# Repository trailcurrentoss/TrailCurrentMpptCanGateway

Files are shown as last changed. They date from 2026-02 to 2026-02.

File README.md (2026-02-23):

# TrailCurrent MPPT CAN Gateway

Gateway module that reads data from a Victron MPPT (Maximum Power Point Tracker) solar charge controller via serial and relays the readings over a CAN bus interface. Part of the [TrailCurrent](https://trailcurrent.com) open-source vehicle platform.

## Hardware Overview

- **Microcontroller:** ESP32
- **Function:** Serial-to-CAN bus bridge for Victron MPPT solar charge controller data
- **Key Features:**
  - Victron MPPT VE.Direct serial protocol parsing
  - CAN bus output at 500 kbps
  - Real-time solar panel monitoring
  - Hierarchical PCB schematic design

## Hardware Requirements

### Components

- **Microcontroller:** ESP32 development board
- **CAN Transceiver:** Vehicle CAN bus interface (TX: GPIO 15, RX: GPIO 13)
- **Serial Input:** Victron MPPT VE.Direct connection (Serial2: TX GPIO 17, RX GPIO 16 at 19200 baud)

### KiCAD Library Dependencies

This project uses the consolidated [TrailCurrentKiCADLibraries](https://github.com/trailcurrentoss/TrailCurrentKiCADLibraries).

**Setup:**

```bash
# Clone the library
git clone git@github.com:trailcurrentoss/TrailCurrentKiCADLibraries.git

# Set environment variables (add to ~/.bashrc or ~/.zshrc)
export TRAILCURRENT_SYMBOL_DIR="/path/to/TrailCurrentKiCADLibraries/symbols"
export TRAILCURRENT_FOOTPRINT_DIR="/path/to/TrailCurrentKiCADLibraries/footprints"
export TRAILCURRENT_3DMODEL_DIR="/path/to/TrailCurrentKiCADLibraries/3d_models"
```

See [KICAD_ENVIRONMENT_SETUP.md](https://github.com/trailcurrentoss/TrailCurrentKiCADLibraries/blob/main/KICAD_ENVIRONMENT_SETUP.md) in the library repository for detailed setup instructions.

## Opening the Project

1. **Set up environment variables** (see Library Dependencies above)
2. **Open KiCAD:**
   ```bash
   kicad EDA/trailer-mppt-can-bus.kicad_pro
   ```
3. **Verify libraries load** - All symbol and footprint libraries should resolve without errors
4. **View 3D models** - Open PCB and press `Alt+3` to view the 3D visualization

### Schematic Sheets

The design uses a hierarchical schematic with dedicated sheets:
- **Root** - Top-level connections
- **Power** - Power distribution and regulation
- **CAN** - CAN bus transceiver interface
- **MCU** - ESP32 microcontroller and support circuits
- **Connectivity** - Serial interface to Victron MPPT

## Firmware

See `src/` directory for PlatformIO-based firmware.

**Setup:**
```bash
# Install PlatformIO (if not already installed)
pip install platformio

# Build firmware
pio run

# Upload to board
pio run -t upload
```

### Victron MPPT Parameters

The firmware parses the following VE.Direct protocol fields:

| Parameter | Description |
|---|---|
| V | Battery voltage |
| VPV | Panel voltage |
| PPV | Panel power (watts) |
| I | Panel current |
| CS | Charge state |
| ERR | Error code |
| H19-H23 | Historical yield and power data |

### CAN Bus Protocol

The gateway transmits two messages at 500 kbps with a 33ms update cycle:

**Message 0x2C** (7 bytes) - Solar panel basics:

| Byte | Description |
|---|---|
| 0-1 | Panel voltage |
| 2-3 | Solar watts |
| 4-5 | Battery voltage |
| 6 | Solar status |

**Message 0x2D** (3 bytes) - Solar current:

| Byte | Description |
|---|---|
| 0 | Current sign |
| 1-2 | Current magnitude |

## Manufacturing

- **PCB Files:** Ready for fabrication via standard PCB services (JLCPCB, OSH Park, etc.)
- **BOM Generation:** Export BOM from KiCAD schematic (Tools > Generate BOM)
- **JLCPCB Assembly:** See [BOM_ASSEMBLY_WORKFLOW.md](https://github.com/trailcurrentoss/TrailCurrentKiCADLibraries/blob/main/BOM_ASSEMBLY_WORKFLOW.md) for detailed assembly workflow

## Project Structure

```
├── EDA/                          # KiCAD hardware design files
│   ├── trailer-mppt-can-bus.kicad_pro
│   ├── trailer-mppt-can-bus.kicad_sch  # Root schematic
│   ├── can.kicad_sch             # CAN subsystem
│   ├── connectivity.kicad_sch    # Serial interface
│   ├── mcu.kicad_sch             # MCU subsystem
│   ├── power.kicad_sch           # Power subsystem
│   └── trailer-mppt-can-bus.kicad_pcb  # PCB layout
├── src/                          # Firmware source
│   ├── main.cpp                  # Victron MPPT parser and CAN transmitter
│   ├── globals.h                 # Debug macros
│   └── canHelper.h               # CAN bus configuration
└── platformio.ini                # Build configuration
```

## License

MIT License - See LICENSE file for details.

This is open source hardware. You are free to use, modify, and distribute these designs under the terms of the MIT license.

## Contributing

Improvements and contributions are welcome! Please submit issues or pull requests.

## Support

For questions about:
- **KiCAD setup:** See [KICAD_ENVIRONMENT_SETUP.md](https://github.com/trailcurrentoss/TrailCurrentKiCADLibraries/blob/main/KICAD_ENVIRONMENT_SETUP.md)
- **Assembly workflow:** See [BOM_ASSEMBLY_WORKFLOW.md](https://github.com/trailcurrentoss/TrailCurrentKiCADLibraries/blob/main/BOM_ASSEMBLY_WORKFLOW.md)

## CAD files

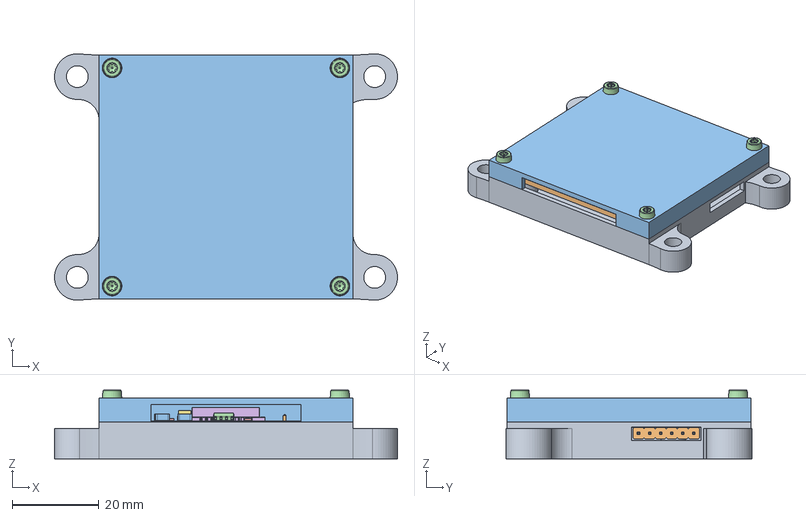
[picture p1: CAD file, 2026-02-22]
CAD/trailcurrent-shunt-can-bus-housing.FCStd
78.9 x 56.7 x 15.8 mm
BodyCaseBottom
Pcb_7b99
C5_C_1206_3216Metric_9f1fbb0e91b7 x 6
U2_SOIC_8_39x49mm_P127mm_3940626bae83
R4_R_1206_3216Metric_6f3765b3a8a0 x 2
AP63203WU-7
AP63203WU-008
AP63203WU-009
AP63203WU-010
AP63203WU-011
AP63203WU-012
AP63203WU-013
AP63203WU-014
U1_ESP32-WROOM-32_805435b90435
FilletPin1
FilletPin2
J1_PinHeader_1x06_P254mm_Horizontal_b900b64528b3
BodyCaseCover
M2.5x8-Screw x 4

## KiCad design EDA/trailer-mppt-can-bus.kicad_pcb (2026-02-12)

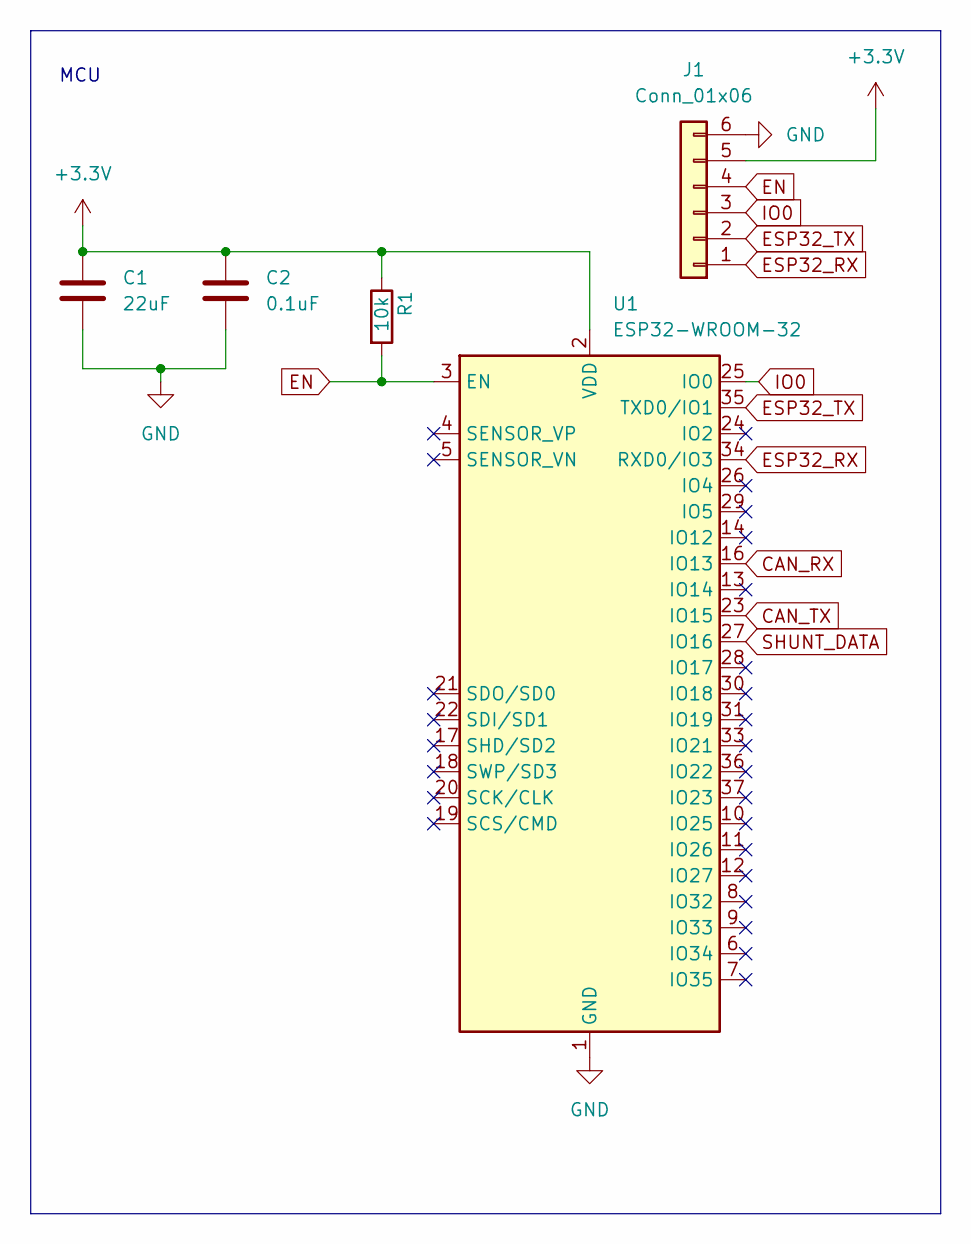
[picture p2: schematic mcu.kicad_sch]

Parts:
C1: 22uF; C_1206_3216Metric_Pad1.33x1.80mm_HandSolder
C2: 0.1uF; C_1206_3216Metric_Pad1.33x1.80mm_HandSolder
J1: Conn_01x06; PinHeader_1x06_P2.54mm_Horizontal
R1: 10k; R_1206_3216Metric_Pad1.30x1.75mm_HandSolder
U1: ESP32-WROOM-32

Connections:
+3.3V: C1.1, C2.1, J1.5, R1.1, U1.2 (VDD); also elsewhere on the board
CAN_RX: U1.16 (IO13); also elsewhere on the board
CAN_TX: U1.23 (IO15); also elsewhere on the board
EN: J1.4, R1.2, U1.3 (EN)
ESP32_RX: J1.1, U1.34 (RXD0/IO3)
ESP32_TX: J1.2, U1.35 (TXD0/IO1)
GND: C1.2, C2.2, J1.6, U1.1 (GND), U1.15 (GND), U1.38 (GND), U1.39 (GND); also elsewhere on the board
IO0: J1.3, U1.25 (IO0)
SHUNT_DATA: U1.27 (IO16); also elsewhere on the board

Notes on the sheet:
MCU

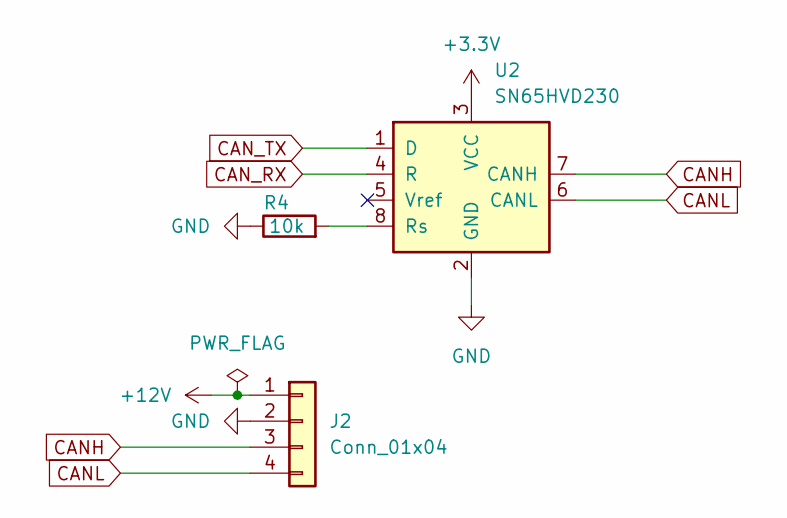
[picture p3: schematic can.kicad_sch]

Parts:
J2: Conn_01x04; CAN_PLUS_POWER
R4: 10k; R_1206_3216Metric_Pad1.30x1.75mm_HandSolder
U2: SN65HVD230; SOIC-8_3.9x4.9mm_P1.27mm

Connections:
+3.3V: U2.3 (VCC); also elsewhere on the board
+12V: J2.1; also elsewhere on the board
CANH: J2.3, U2.7 (CANH)
CANL: J2.4, U2.6 (CANL)
CAN_RX: U2.4 (R); also elsewhere on the board
CAN_TX: U2.1 (D); also elsewhere on the board
GND: J2.2, R4.1, U2.2 (GND); also elsewhere on the board
unnamed: R4.2, U2.8 (Rs)

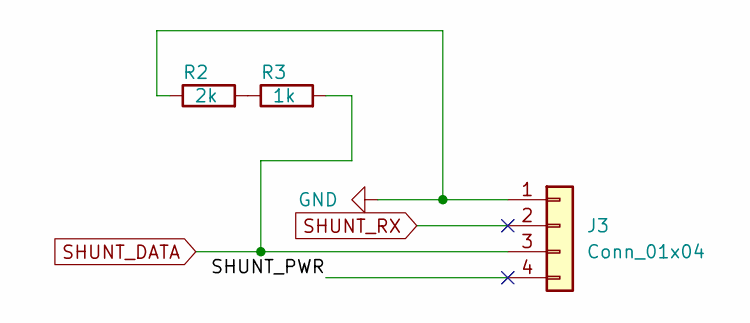
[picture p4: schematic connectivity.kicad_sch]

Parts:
J3: Conn_01x04; GenericPad_01x04
R2: 2k; R_1206_3216Metric_Pad1.30x1.75mm_HandSolder
R3: 1k; R_1206_3216Metric_Pad1.30x1.75mm_HandSolder

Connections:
/Connectivity/SHUNT_PWR: J3.4
GND: J3.1, R2.1; also elsewhere on the board
unnamed: R2.2, R3.1
SHUNT_DATA: J3.3, R3.2; also elsewhere on the board
SHUNT_RX: J3.2

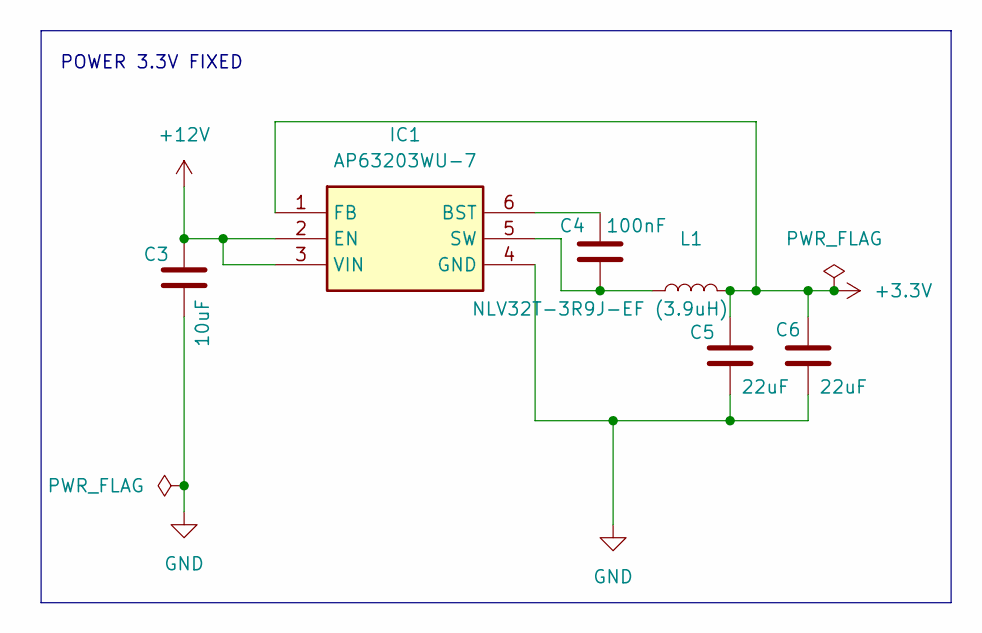
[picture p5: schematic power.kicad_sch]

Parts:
C3: 10uF; C_1206_3216Metric
C4: 100nF; C_1206_3216Metric
C5, C6: 22uF; C_1206_3216Metric_Pad1.33x1.80mm_HandSolder
IC1: AP63203WU-7; AP63203WU7; Mouser Part Number 621-AP63203WU-7
L1: NLV32T-3R9J-EF (3.9uH); NLV32T-3R9J-EF

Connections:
+3.3V: C5.1, C6.1, IC1.1 (FB), L1.2; also elsewhere on the board
+12V: C3.1, IC1.2 (EN), IC1.3 (VIN); also elsewhere on the board
GND: C3.2, C5.2, C6.2, IC1.4 (GND); also elsewhere on the board
unnamed: C4.1, IC1.6 (BST)
unnamed: C4.2, IC1.5 (SW), L1.1

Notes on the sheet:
POWER 3.3V FIXED

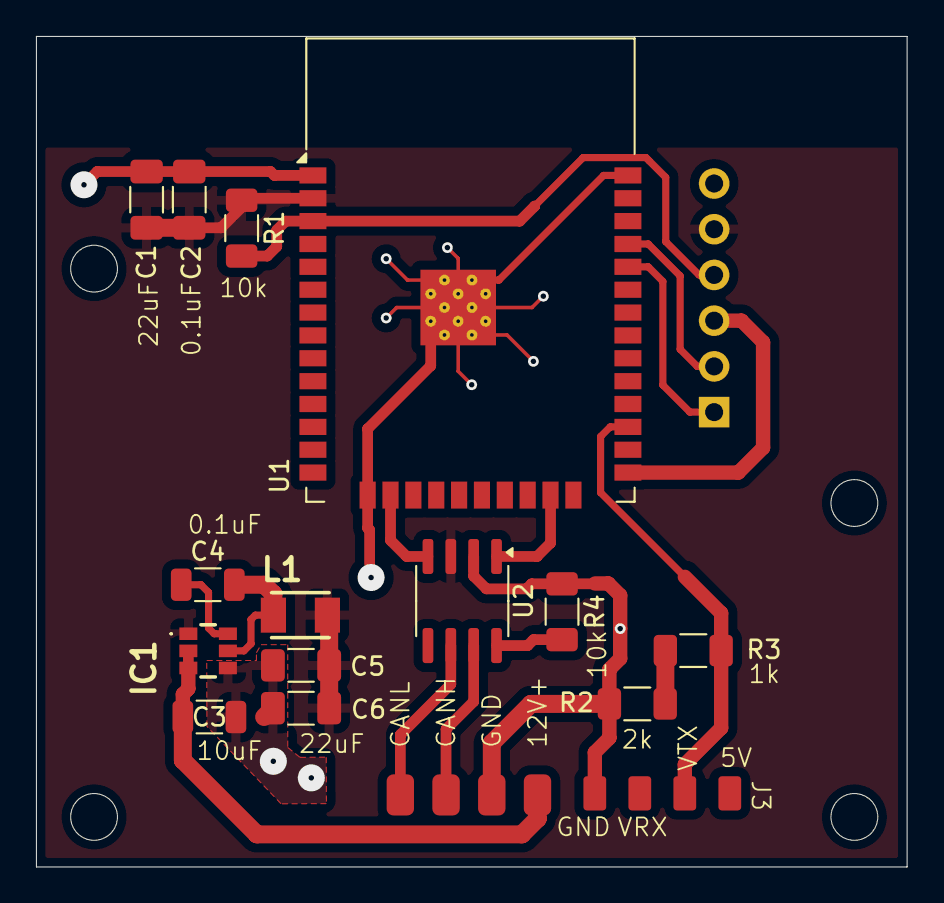
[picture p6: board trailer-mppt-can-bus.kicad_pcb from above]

Board: 2 copper layers, 48.4 x 46.1 mm, 17 parts (1 on the bottom side), 16 nets.

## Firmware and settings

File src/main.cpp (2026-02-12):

#include <Arduino.h>
#include "globals.h"
#include "canHelper.h"

#define CAN_SEND_MESSAGE_SOLAR01_IDENTIFIER 0x2C;
#define CAN_SEND_MESSAGE_SOLAR02_IDENTIFIER 0x2D;
volatile int panelVoltageWholeNumber;
volatile int panelVotlageDecimal;
volatile byte solarWattageMsb;
volatile byte solarWattageLsb;
volatile int batteryVoltageWholeNumber;
volatile int batteryVotlageDecimal;
volatile int isPanelCurrentNegative;
volatile int panelCurrentWholeNumber;
volatile int panelCurrentDecimal;
volatile int solarStatus;

unsigned long canStartMillis;
unsigned long canCurrentMillis;
const unsigned long canStatusPeriod = 33;

void setup()
{
  Serial.begin(115200); // Used for debugging and logging
  while (!Serial)
  {
    ;
    ;
  }
  Serial2.begin(19200); // RX on pin 16, TX on pin 17
  canHelper::canSetup();
}

static void send_mppt_message()
{
  // Configure message to transmit
  twai_message_t message;
  message.identifier = CAN_SEND_MESSAGE_SOLAR01_IDENTIFIER;
  message.extd = false;
  message.rtr = false;
  message.data_length_code = 7;
  message.data[0] = panelVoltageWholeNumber;
  message.data[1] = panelVotlageDecimal;
  message.data[2] = solarWattageMsb;
  message.data[3] = solarWattageLsb;
  message.data[4] = batteryVoltageWholeNumber;
  message.data[5] = batteryVotlageDecimal;
  message.data[6] = solarStatus;
  // Queue message for transmission
  if (twai_transmit(&message, pdMS_TO_TICKS(10)) == ESP_OK)
  {
    debugln("Message queued for transmission");
  }
  else
  {
    debugln("Failed to queue message for transmission");
  }
  return;
}

static void send_mppt_message2()
{
  // Configure message to transmit
  twai_message_t message;
  message.identifier = CAN_SEND_MESSAGE_SOLAR02_IDENTIFIER;
  message.extd = false;
  message.rtr = false;
  message.data_length_code = 3;
  message.data[0] = isPanelCurrentNegative;
  message.data[1] = panelCurrentWholeNumber;
  message.data[2] = panelCurrentDecimal;
  // Queue message for transmission
  if (twai_transmit(&message, pdMS_TO_TICKS(10)) == ESP_OK)
  {
    debugln("Message queued for transmission");
  }
  else
  {
    debugln("Failed to queue message for transmission");
  }
  return;
}

void loop()
{
  canCurrentMillis = millis();
  if (canCurrentMillis - canStartMillis >= canStatusPeriod)
  {
    Serial.println("Running");
    while (Serial2.available())
    {
      String input = Serial2.readStringUntil('\n');
      Serial.println(input);
      // Split the input string based on the delimiter "]t"
      int startIndex = 0;
      int delimiterIndex = 0;

      while ((delimiterIndex = input.indexOf("\t", startIndex)) != -1)
      {
        // Extract the key (substring from startIndex to delimiterIndex)
        String key = input.substring(startIndex, delimiterIndex);
        startIndex = delimiterIndex + 1; // Move past the "]t" delimiter

        // Extract the value (substring from startIndex to the next delimiter or end of string)
        int nextDelimiterIndex = input.indexOf("\t", startIndex);
        String value;
        if (nextDelimiterIndex != -1)
        {
          value = input.substring(startIndex, nextDelimiterIndex);
          startIndex = nextDelimiterIndex + 2; // Move past the "]t" delimiter
        }
        else
        {
          value = input.substring(startIndex); // Handle last key-value pair (no delimiter after value)
        }
        // Serial.print("Key ");
        // Serial.println(key);
        // Serial.print("Value: ");
        // Serial.println(value);
        if (key == "V")
        {
          float voltageValue = (value.toInt() * 0.001);
          batteryVoltageWholeNumber = (int)voltageValue;                                   // First we get the whole number voltage.
          batteryVotlageDecimal = (int)((voltageValue - batteryVoltageWholeNumber) * 100); // For 2 decimal places          
        }
        else if (key == "VPV")
        {
          float panelVoltageValue = (value.toInt() * 0.001);
          panelVoltageWholeNumber = (int)panelVoltageValue;                                 // First we get the whole number voltage.
          panelVotlageDecimal = (int)((panelVoltageValue - panelVoltageWholeNumber) * 100); // For 2 decimal places
        }
        else if (key == "PPV") // This is the panel power
        {
          int solarWattage = value.toInt();
          // Break the absolute value into 2 bytes
          byte lowByte = solarWattage & 0xFF;         // Least significant byte
          byte highByte = (solarWattage >> 8) & 0xFF; // Most significant byte          
          solarWattageMsb = highByte;
          solarWattageLsb = lowByte;
        }
        else if (key == "I")
        {
          float panelCurrentValue = (value.toInt() * 0.001);
          panelCurrentWholeNumber = (int)panelCurrentValue;
          panelCurrentDecimal = (int)((panelCurrentValue - panelCurrentWholeNumber) * 100);
          if (panelCurrentValue < 0)
          {
            isPanelCurrentNegative = 1;
          }
          else
          {
            isPanelCurrentNegative = 0;
          }
        }
        else if (key == "LOAD")
        {
          Serial.print("Panel Load: "); // ON or OFF in string
          Serial.println(value);
        }
        else if (key == "H19")
        {
          float yieldTotal = (value.toInt() * 0.01);
          Serial.print("Yield Total: ");
          Serial.print(yieldTotal);
          Serial.println(" Kw");
        }
        else if (key == "H20")
        {
          float yieldToday = (value.toInt() * 0.01);
          Serial.print("Yield Today: ");
          Serial.print(yieldToday);
          Serial.println(" Kw");
        }
        else if (key == "H21")
        {
          float maxPowerToday = value.toInt();
          Serial.print("Maximum Power Today: ");
          Serial.print(maxPowerToday);
          Serial.println(" W");
        }
        else if (key == "H22")
        {
          float yieldYesterday = (value.toInt() * 0.01);
          Serial.print("Yield Yesterday: ");
          Serial.print(yieldYesterday);
          Serial.println(" Kw");
        }
        else if (key == "H23")
        {
          float maxPowerYesterday = value.toInt();
          Serial.print("Maximum Power Yesterday: ");
          Serial.print(maxPowerYesterday);
          Serial.println(" W");
        }
        else if (key == "ERR")
        {
          Serial.print("Error: "); // Lookup values in ERR of documentation
          Serial.println(value);
        }
        else if (key == "CS")
        {
          // Indicates enum values of charging, etc...
          solarStatus = value.toInt();
        }
        else if (key == "FW")
        {
          Serial.print("Firmware Version: ");
          Serial.println(value);
        }
        else if (key == "PID")
        {
          Serial.print("Product ID: ");
          Serial.println(value);
        }
        else if (key == "SER#")
        {
          Serial.print("Serial Number: ");
          Serial.println(value);
        }
        else if (key == "HSDS")
        {
          Serial.print("Day Number: ");
          Serial.println(value);
        }
        else if (key == "MPPT")
        {
          Serial.print("Tracker Mode: "); // See documentation for ENUMS
          Serial.println(value);
        }
      }
    }
    canHelper::canLoop();
    send_mppt_message();
    send_mppt_message2();
    canStartMillis = canCurrentMillis;
  }
}

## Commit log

2026-02-12 Starting project
    [can.kicad_sch, connectivity.kicad_sch, mcu.kicad_sch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]
2026-02-22 Updated housing to have logo
    [trailcurrent-shunt-can-bus-housing.FCStd]
